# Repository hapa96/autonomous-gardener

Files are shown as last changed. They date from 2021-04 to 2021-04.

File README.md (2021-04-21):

# IoT Engineering
## Project: Autonomous Gardener

## Introduction
This project is part of the [IoT Engineering](../../../fhnw-iot) course.

* 2-person teams, building an IoT system.
* 32 hours of work per person, 1 prototype.
* 10' presentation of the project at Demo Day.
* Slides, source code and setup steps on GitHub.
* Both team members are able to explain the project.

### Team members
* @hapa96, [Pascal Hauser](mailto:pascal.hauser1@students.fhnw.ch)
* @McSquanchy, [Kevin Buman](mailto:kevin.buman@students.fhnw.ch)

## Deliverables
The following deliverables are mandatory.

### Source code

[RaspberryPi/main.py](raspberrypi/main.py)

[backend/mqtt/influxdb/docker-compose.yml](backend/mqtt/influxdb/docker-compose.yml)

[backend/mqtt/mosquitto/docker-compose.yml](backend/mqtt/mosquitto/docker-compose.yml)

[backend/traefik/docker-compose.yml](backend/traefik/docker-compose.yml)

[backend/nodered/docker-compose.yml](backend/nodered/docker-compose.yml)

Node-RED Flows:

[documentation/nodered_flows/flows.json](documentation/nodered_flows/flows.json)

### Process Documentation

#### Hardware
##### Wood Case
In the early steps of the project, we noticed, that the soil moisture sensor is not very acurate, when it is placed on the top of a plant. So we needed a case, where we can put the sensor in the upper half of the soil instead of just place it from top. To have a case, which is fulfilling the needs of our project idea, we decided to create a proper wood-case. Luckily, we have a solid workshop with all the tools at home. The following picture shows you the rough process of the case creation.
Wod Case Process

To ensure a good water flow, the soil should be structured in different layers of sand, stones and gardener soil. On the bottom of the case, we installed a jar to collect the water. Thanks to this design, it's possible to have the case inside the house or a balcony without dirt or water on the ground. 

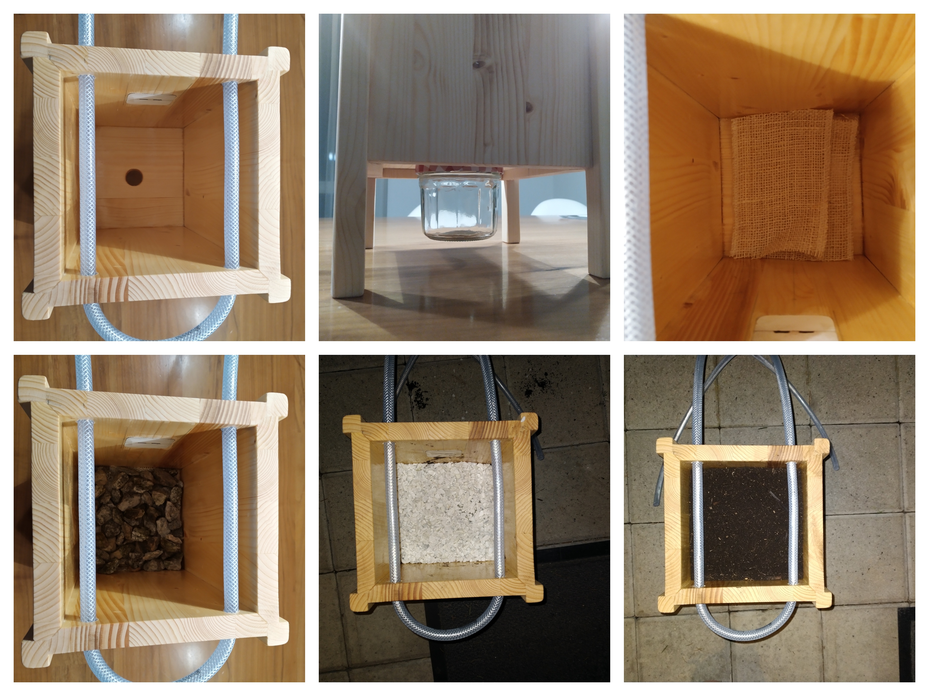
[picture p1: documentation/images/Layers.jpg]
Layers


##### Electronics
For assembly and development of the electronic parts, we used the little electronic workshop in our basement, which provides the basic tools.
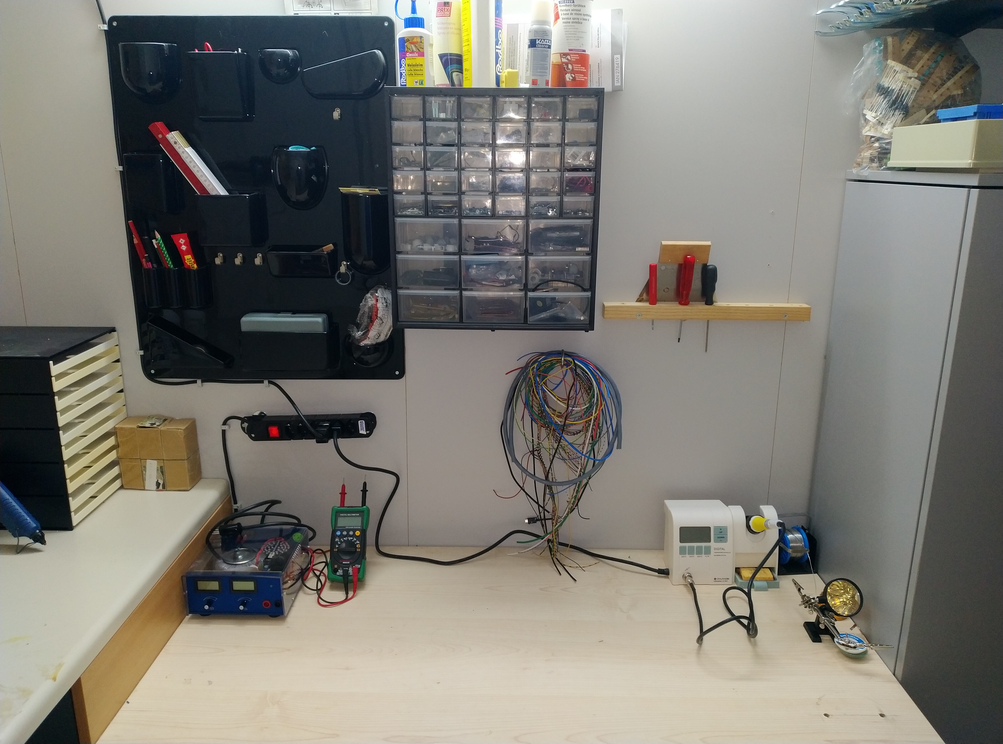
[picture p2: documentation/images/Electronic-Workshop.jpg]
Electronic Workshop


All the electronic parts are collected within a plastic lunch box from IKEA. With this approach, our product can easily placed outdoor and withstand rain and other environmental influences. Following a list of all electronic components that are used:

* [Moisture Sensor](https://wiki.seeedstudio.com/Grove-Moisture_Sensor)
* [12V brushless DC Motor](https://www.banggood.com/Mini-DC12V-3M-Micro-Quiet-Brushless-Motor-Submersible-Water-Pump-p-1182617.html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)
* [Raspberry Pi Zero](https://www.raspberrypi.org/products/raspberry-pi-zero/)
* [Grove Base Hat for Raspberry Pi Zero](https://wiki.seeedstudio.com/Grove_Base_Hat_for_Raspberry_Pi_Zero/)
* [230V/12V 5A AC/DC Converter](https://www.seeedstudio.com/12V5A-Power-adapter.html)
* [Darlington Transistor ULN2803](https://www.conrad.de/de/ratgeber/handwerk-industrie-wiki/elektronik-bauteile/uln2803.html)

The final result looks as following:
Final Electronics

Here you can see the circuit for the electronics:

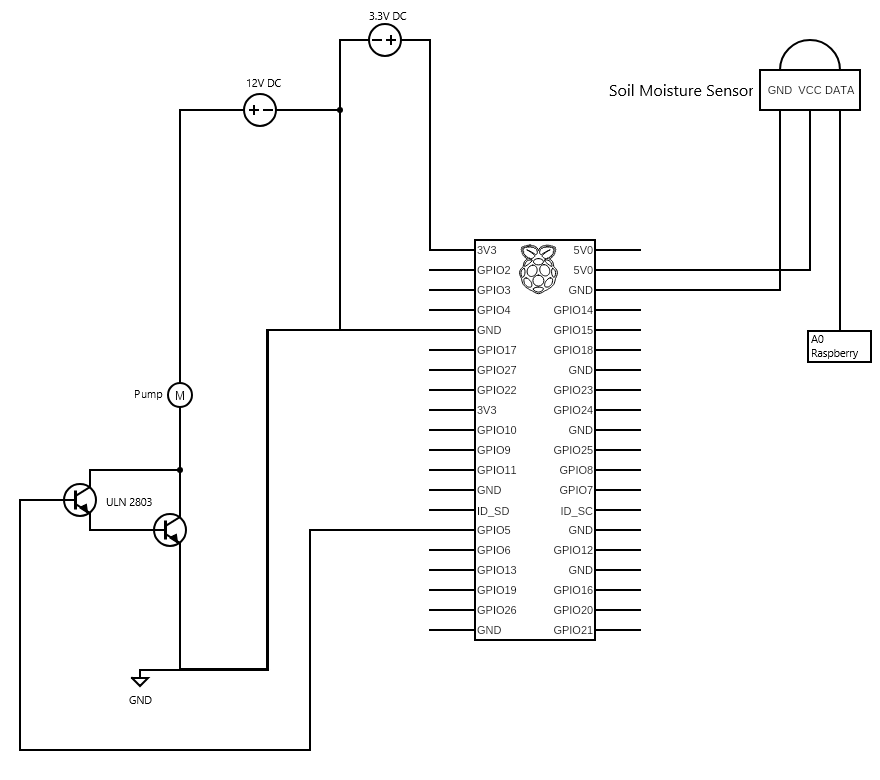
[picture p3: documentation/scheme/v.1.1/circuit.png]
circuit


#### Backend

**Strategy**: We decided to use MQTT as our transport protocol for communication between the local device, a Raspberry Pi, and our cloud backend. The backend runs on a Linux VM from [Switch](https://www.switch.ch/engines/).

Since our goal was to have multiple services running on the same host, decided to go for a container-based solution, running on docker-swarm. This made it possible to deploy each service as its own stack, making things much easier to manage.

**Services**: The following section describes each service and its purpose. Each service requires a login. For simplicity, username and password are the same across all of them:

* Username: **admin**
* Password: **iotproject20**

*Note*: each service has its own ```docker-compose``` file and is deployed as a stack using ```docker swarm```.

**Application & Network Security**: We used the free part of [Cloudflare](https://www.cloudflare.com/)'s suite to protect our application. Cloudflare acts as our DNS server. It's important to note that Cloudflare only routes packets on certain ports, while blocking everything else. This put some constraints on our design, for example: Since port *8443* for MQTT is not supported, we had to use *websockets* for all of our MQTT traffic.

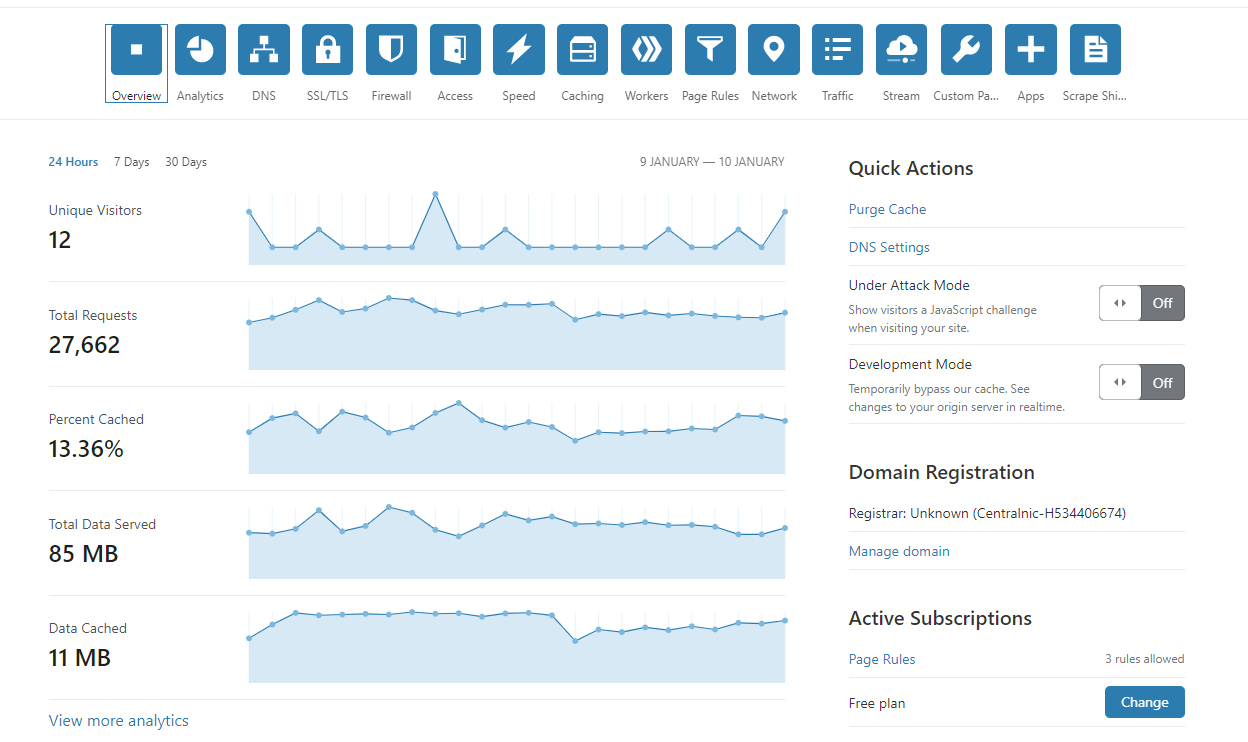
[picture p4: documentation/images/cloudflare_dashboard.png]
cloudflare_dashboard


**Gateway**: [Traefik](https://traefik.io/traefik/) is an application proxy which routes and forwards incoming requests to specified services. It also acts as a security layer, preventing direct access to any service sitting behind it.  
Using Traefik made it very simple to configure and monitor all services and routes.

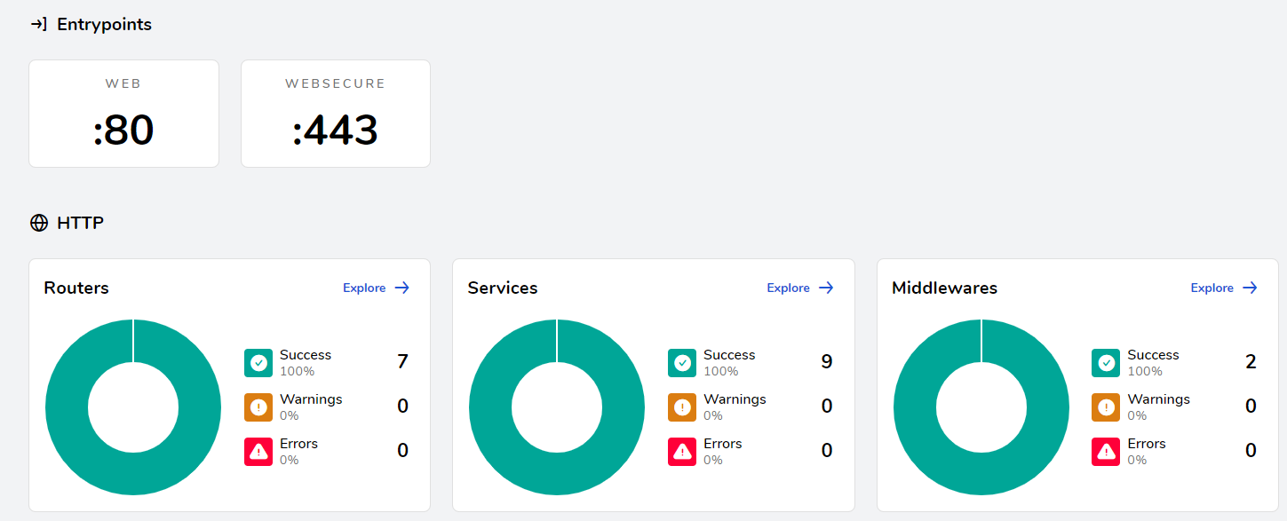
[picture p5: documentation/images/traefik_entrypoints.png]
traefik_ui


[Traefik Dashboard](https://traefik.autonomous-gardener.tech/)

**MQTT-Broker**: We used [Mosquitto](https://hub.docker.com/_/eclipse-mosquitto) as our MQTT broker. As mentioned above, we configured it to use websockets. This way traffic is routed properly by Cloudflare using port **443**. Traefik reroutes packets to port **9001** on the target container.

**Application Logic**: We leveraged [Node-RED](https://nodered.org/)'s extensive featureset to implement our businesslogic. Multiple *mqtt in* nodes subscribe to various topics, process messages, and store them in our database. Its also here where communication from the backend to the local device takes place. Our flows dynamically broadcast trigger messages over mqtt upon fulfilling pre-defined criteria.

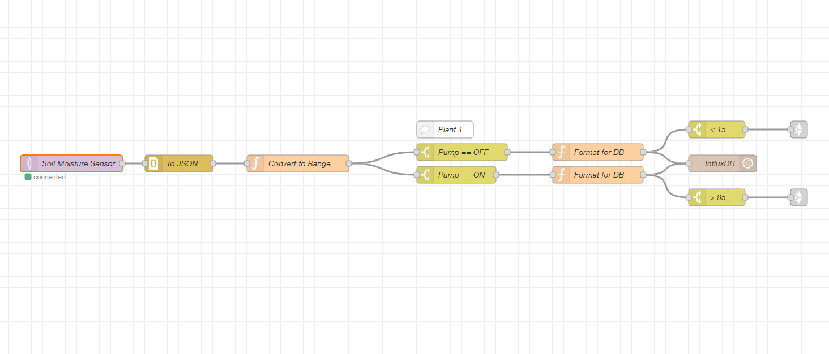
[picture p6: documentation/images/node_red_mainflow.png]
node_flow


[Node-RED Dashboard](https://nodered.autonomous-gardener.tech/)

**Database**: Since soil moisture is measured periodically, we chose to use [InfluxDB](https://www.influxdata.com/) as our database. This makes it very easy to query data in many different ways, which is ideal for monitoring.

**Monitoring**: We went with [Grafana](https://grafana.com/) for our monitoring solution. It can directly access our data inside InfluxDB and allows us to define alle kinds of querys.

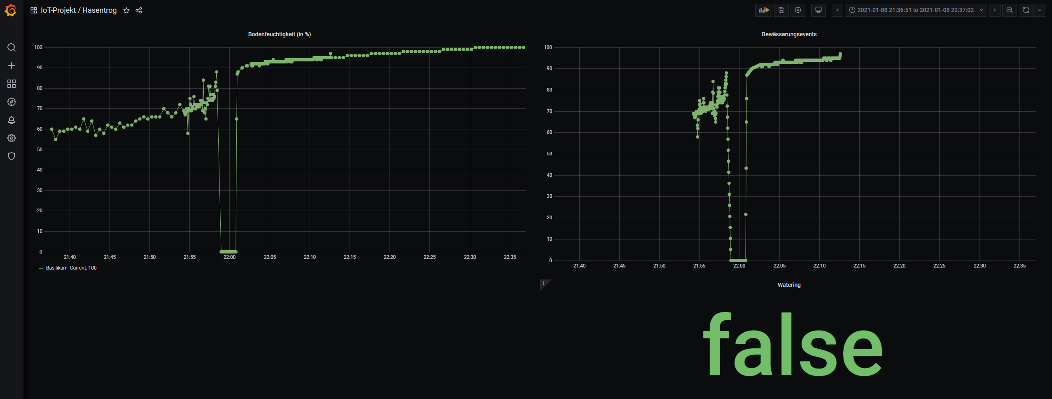
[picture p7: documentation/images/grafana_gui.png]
grafana_dashboard


[Grafana Dashboard Dashboard](https://grafana.autonomous-gardener.tech/)

#### Frontend

The frontend consists of a Raspberry Pi running ```Raspbian```. The entire application is written in ```Python```. It's capable of taking sensor readings, sending them to our backend, as well as turning the water pump on and off based on commands sent by the backend.  
To increase convenience, we added basic quality of life features. These include:

* If offline, sensor readings are stored in a file. If internet connectiviy ist re-established, the script will first push any locally stored readings to the backend, maintaining a clean record inside the database.
* Measurement frequencies are stored in a ```config.json``` file. In addition, the script fetches the latest config from the backend during startup.
* New configs can be configured in *Node-RED* and deployed remotely. The script will then update its ```config.json``` file with the new settings.
* The pump can be manually triggered using a separate *Node-RED* flow.

### Presentation

[documentation/slides/iot_project_hauser_buman_slides.pdf](documentation/slides/iot_project_hauser_buman_slides.pdf)

### Live demo

* The video for the live demo is available [here](https://tube.switch.ch/embed/9f79759f).
* See [Backend](#Backend) for links to each service.

## Submission deadline
Commit and push to (this) project repo before Demo Day, _11.01.2021, 00:00_.

# Project Idea
[Initial Project Idea](./documentation/Initial-Project-Idea.pdf)

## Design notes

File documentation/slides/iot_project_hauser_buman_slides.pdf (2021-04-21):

### Semesterprojekt IoT – HS 2020

# Autonomous Gardener

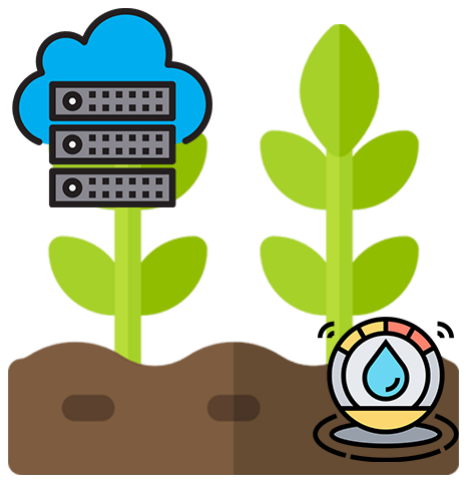
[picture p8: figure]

### Pascal Hauser Kevin Buman

Internet of Things | 10.01.2021 | 2

Use Case

- Optimize plant watering systems:
- Define custom watering schedules using
- Time
- Numeric thresholds
- Runs automatically, ideal for people who travel regularly
- Optimize water usage by providing the right amount for each plant.
- Easy scaling to multiple plants and even multiple pumps
- 24 / 7 monitoring with clean interface and easy access over any web browser

Reference Model

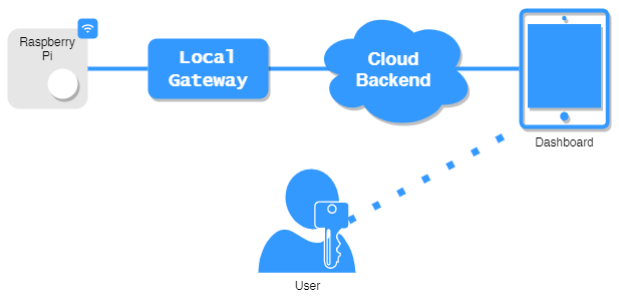
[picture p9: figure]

Setup

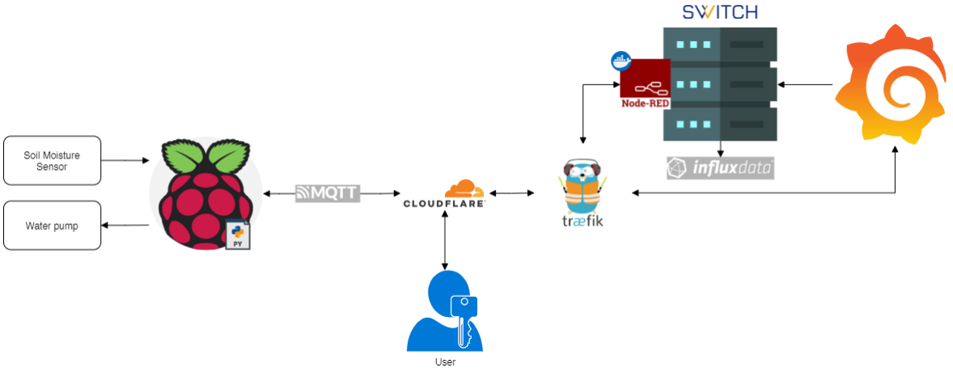
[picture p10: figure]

Issues

- Sensor values volatile
- Sensor is used during watering events
- non deterministic
- hard to get right

Possible Solutions

- Deliver predefined amount of water over time.
- This way, we do not depend on the volatile sensor readings and only use the sensor for monitoring
- Try with a different Sensor and experiment with sensor positioning

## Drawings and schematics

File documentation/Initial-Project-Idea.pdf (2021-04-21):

## Arduino

# Autonomous Gardener

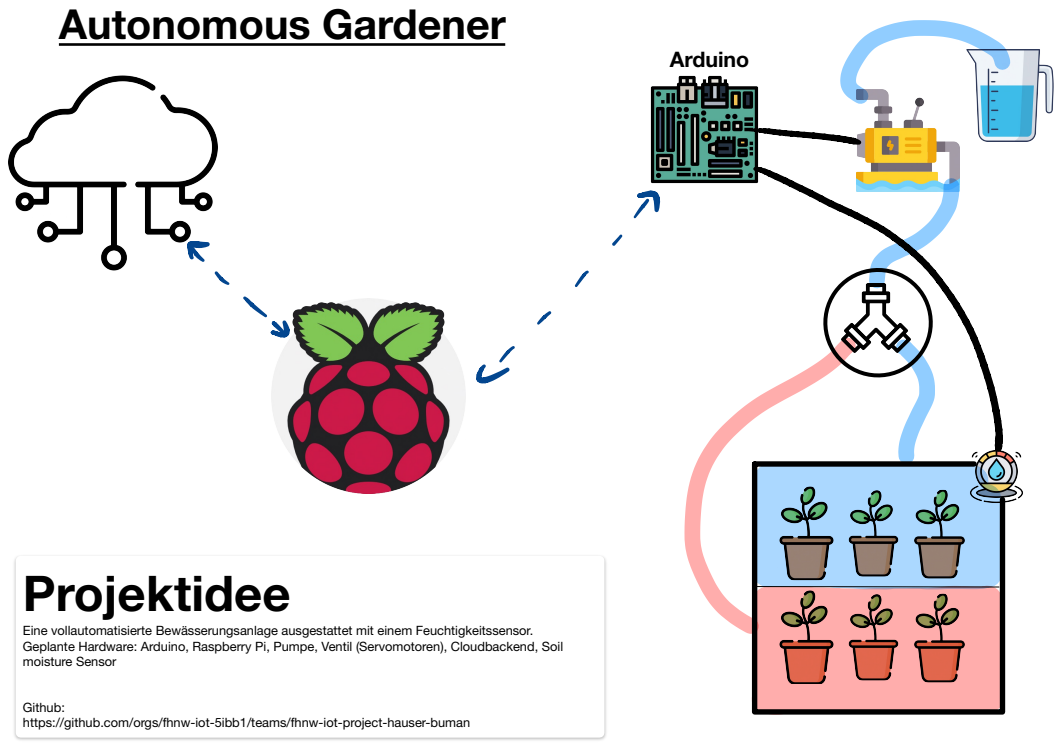
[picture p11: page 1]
Projektidee

Eine vollautomatisierte Bewässerungsanlage ausgestattet mit einem Feuchtigkeitssensor.
Geplante Hardware: Arduino, Raspberry Pi, Pumpe, Ventil (Servomotoren), Cloudbackend, Soil
moisture Sensor

Github:
https://github.com/orgs/fhnw-iot-5ibb1/teams/fhnw-iot-project-hauser-buman

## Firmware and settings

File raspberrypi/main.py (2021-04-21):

import time
import math
import paho.mqtt.client as mqtt
import json
import socket
import tempfile
import sys
from Logger import Logger

from grove.grove_moisture_sensor import GroveMoistureSensor
from grove.gpio import GPIO

S1_IDLE_FREQUENCY = 3600
S1_WATERING_FREQUENCY = 30

logger = Logger(0)

# Define Variables for Raspberry Pi

sensor = GroveMoistureSensor(0)
pump = GPIO(5, GPIO.OUT)

# Watering Flag
pumpWatering = False

BROKER_URL = "mqtt.autonomous-gardener.tech"


def on_connect(client, userdata, flags, rc):
    """
    Called when the broker responds to our connection request.
    client: The client instance for this callback
    userdata: The private user data as set in Client() or user_data_set()
    flags: Response flags sent by the broker
    rc: The connection result
    """
    if rc == 0:
        client.connected_flag = True  # set flag
        logger.log("{} connected".format(client))
    else:
        logger.log("Bad connection Returned code=", rc)


def on_disconnect(client, userdata, rc):
    client.connected_flag = False
    logger.log("Disconnected")


def on_publish(client, userdata, mid):
    logger.log("Publishing message to broker")


def connect_client(client):
    global logger
    """
    Connect a client to the Broker Service and sets all the required tls settings
    """
    client.username_pw_set("fhnw", "iotproject20")
    client.on_connect = on_connect
    client.tls_set()
    logger.log("Connecting to broker " + BROKER_URL)
    client.connect(BROKER_URL, port=443, keepalive=60)


def handle_message(client, userdata, message):
    global logger
    global S1_IDLE_FREQUENCY
    global S1_WATERING_FREQUENCY
    global pumpWatering

    if message.topic == "update-config":
        logger.log("Parsing config")
        new_config = json.loads(message.payload.decode('utf-8'))
        changed = False

        if new_config["sensors"][0]["s1"]["idle_frequency"] != S1_IDLE_FREQUENCY:
            logger.log("Updating idle frequency of S1. New Value: " +
                       str(new_config["sensors"][0]["s1"]["idle_frequency"]))
            S1_IDLE_FREQUENCY = int(
                new_config["sensors"][0]["s1"]
                ["idle_frequency"])
            changed = True

        if new_config["sensors"][0]["s1"]["watering_frequency"] != S1_WATERING_FREQUENCY:
            logger.log(
                "Updating watering frequency of S1. New Value: " +
                str(new_config["sensors"][0]["s1"]["watering_frequency"]))
            S1_WATERING_FREQUENCY = int(new_config["sensors"][0]["s1"][
                "watering_frequency"])
            changed = True

        if changed:
            logger.log("Saving configuration to config.json")
            with open('config/config.json', 'w') as outfile:
                json.dump(new_config, outfile)
        else:
            logger.log("config unchanged")

    else:
        print("New Message from control-hasentrog {}".format(message.payload))
        value = str(message.payload)
        if (value == 'p1-on'):
            pumpWatering = True
            pump.write(1)
            logger.log("turning on pump")

        elif (value == 'p1-off'):
            pumpWatering = False
            pump.write(0)
            logger.log("turning off pump")
        # # MQTT Settings
        # # Publisher


def print_config_load(sensor, val1, val2):
    global logger
    logger.log("Loaded value for " + sensor + " - IDLE: " + str(val1) +
               " / WATERING: " + str(val2))


def set_config_from_file():
    global logger
    global S1_IDLE_FREQUENCY
    global S1_WATERING_FREQUENCY

    logger.log("no connection to servers, loading config from file")
    # Opening JSON file
    f = open('config/config.json',)
    # returns JSON object as
    # a dictionary
    config = json.load(f)

    S1_IDLE_FREQUENCY = int(config["sensors"][0]["s1"]["idle_frequency"])
    S1_WATERING_FREQUENCY = int(
        config["sensors"][0]["s1"]["watering_frequency"])
    print_config_load("S1", S1_IDLE_FREQUENCY, S1_WATERING_FREQUENCY)


def is_connected(hostname):
    try:
        # see if we can resolve the host name -- tells us if there is
        # a DNS listening
        host = socket.gethostbyname(hostname)
        # connect to the host -- tells us if the host is actually
        # reachable
        s = socket.create_connection((host, 80), 2)
        s.close()
        return True
    except:
        pass
    return False


def check_for_dumped_values(broker):
    global logger
    data = {}
    try:
        with open('tmp.json', "r") as json_file:
            data = json.load(json_file)
            if data['measurements']:
                if len(data['measurements']) > 0:
                    logger.log("updating broker")
                    broker.publish("was-offline", json.dumps(data))
                    logger.log("cleaning up tmpfile")
                    init_tmpfile()

    except IOError:
        logger.log("file not found, creating...")
        init_tmpfile()


def main_loop(broker):
    global logger
    global S1_IDLE_FREQUENCY
    global S1_WATERING_FREQUENCY
    global pumpWatering
    last_time = time.time()

    while True:

        next_time = last_time + (S1_IDLE_FREQUENCY
                                 if not pumpWatering else S1_WATERING_FREQUENCY)

        humidity = sensor.moisture
        res = {
            "time": int(round(time.time() * 1000000000)),
            "location": "hasentrog",
            "sensors":
            {"s1": {"moisture": humidity, "pump": pumpWatering}}
        }
        resJSON = json.dumps(res)
        if broker.connected_flag:
            check_for_dumped_values(broker)
            client_publisher.publish("iot-project", resJSON)
        else:
            logger.log("Value: " + str(humidity) + " - saving to file")
            data = {}
            with open('tmp.json', "r") as json_file:
                data = json.load(json_file)
            with open('tmp.json', "w") as json_file:
                data['measurements'].append(res)
                json.dump(data, json_file)
        while(next_time > last_time):
            last_time = time.time()


def init_tmpfile():
    empty_data = {"measurements": []}

    with open('tmp.json', 'w') as outfile:
        json.dump(empty_data, outfile)


if __name__ == "__main__":
    if len(sys.argv) > 2 or (len(sys.argv) == 2 and sys.argv[-1] != "-v"):
        logger.log("Wrong arguments passed")
        sys.exit(2)
    elif len(sys.argv) == 2:
        logger.VERBOSITY = 1

    # Setup MQTT CLIENT
    client_publisher = mqtt.Client(transport="websockets")
    client_publisher.on_disconnect = on_disconnect
    client_publisher.on_publish = on_publish
    client_publisher.connected_flag = False
    client_subscriber = mqtt.Client(transport="websockets")
    client_subscriber.on_message = handle_message
    client_subscriber.on_disconnect = on_disconnect
    client_subscriber.connected_flag = False

    if is_connected(BROKER_URL):

        # Subscribers
        connect_client(client_subscriber)
        client_subscriber.subscribe("update-config")
        client_subscriber.subscribe("control-pump")
        client_subscriber.loop_start()

        connect_client(client_publisher)
        client_publisher.loop_start()

        # safety-pause
        time.sleep(2)

        client_publisher.publish("fetch-config")
    else:
        set_config_from_file()
        logger.log("no connection to servers, saving to file")

    # safety-pause
    time.sleep(2)

    main_loop(client_publisher)
